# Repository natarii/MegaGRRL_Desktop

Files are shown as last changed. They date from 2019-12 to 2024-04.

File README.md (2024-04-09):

# MegaGRRL Desktop
## Overview
**MegaGRRL Desktop** is a simplified, easier to assemble respin of the original MegaGRRL project. This is intended for those who wish to assemble their own with minimal surface mount soldering, or do not need portability.
## Assembly guide
[Click here for the assembly guide.](https://git.agiri.ninja/natalie/MegaGRRL_Desktop/wikis/Assembly-guide) Bill of materials can be found [here](https://git.agiri.ninja/natalie/MegaGRRL_Desktop/wikis/BOM)
## Firmware flashing/changes
The portable and desktop MegaGRRL versions share a single codebase, contained in the [normal MegaGRRL repo](https://git.agiri.ninja/natalie/megagrrl). Before compiling, `main/hal.h` must be edited to specify that the desktop version is built. More details on this are available in the MegaGRRL project repo's readme.

A simplified flashing guide is available for Windows users [here](https://git.agiri.ninja/snippets/3).
## PCB manufacturing considerations
The board is a fairly standard 2-layer board. Please ensure that your PCB manufacturer handles the plated slots on the headphone jack correctly. The DRC rules are set for tented vias - these are preferable for aesthetics, but are otherwise not required. Please note if exporting your own gerbers that the art for the top and bottom of the PCB are on layers 200 (top) and 201 (bottom). Pre-exported gerbers for JLCPCB can be found in the `gerbers/` directory.
## 3D Printing
`mgd_base.stl` is an STL file for a 3D-printable baseplate for the MegaGRRL Desktop board. This provides a nice flat bottom surface and also supports the PCB underneath areas that undergo flexing (buttons, IC sockets). The original OpenSCAD source file is also available. 100% infill is recommended, and printing with a brim may help bed adhesion. Supports are needed due to the recessed screw holes. **The STL and SCAD files have recently been updated to be sized in mm instead of mil.** Previously they required scaling before printing, but this should no longer be required. If you are using a paid 3D printing service, please double-check the size before ordering!
## License
The schematic, PCB, and baseplate are licensed under CERN-OHL-S v2.
## Beware Fake Chips!

[WIP guide on detecting fake chips](https://git.agiri.ninja/natalie/MegaGRRL_Desktop/-/wikis/Identifying-fake-YM2612s)

Many of the YM2612s being sold on eBay are fake. Chips are very often remarked to make them appear new, and that has been ongoing for a long time, but recently myself and friends have received completely fake, non-working chips from multiple eBay sellers. If you are unsure about chips you received, email me a photo and I'll check them out. Also, I have had much better luck receiving legit YM3438s from eBay, so that may be the way to go. I recommend YM3438 anyway due to its improved sound quality.

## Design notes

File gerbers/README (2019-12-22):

This directory contains pre-made gerber files. They have not been tested with any PCB fab other than JLCPCB. Use at your own risk! It is recommended to export your own gerbers and ensure they match your fab's specs.

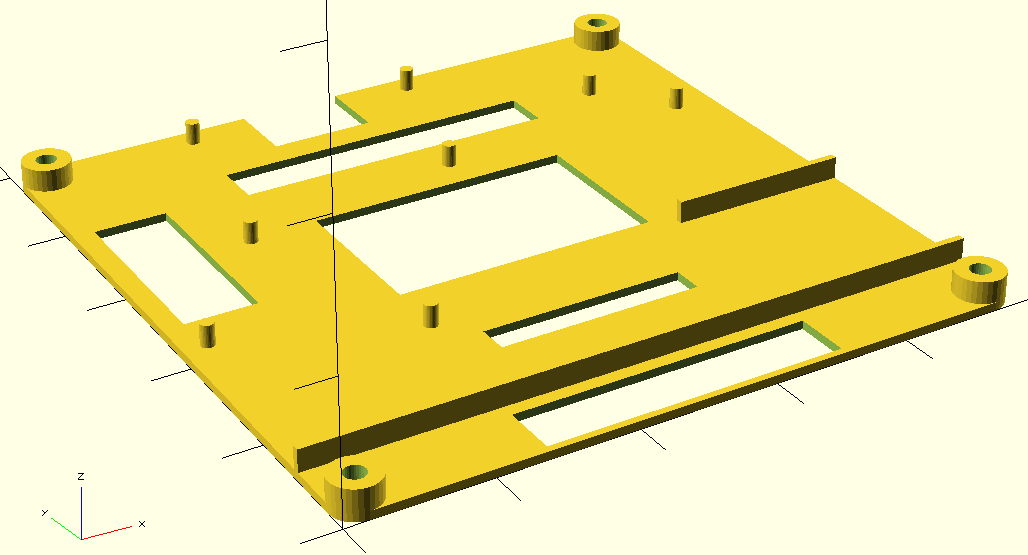
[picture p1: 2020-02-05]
mgd_base.png

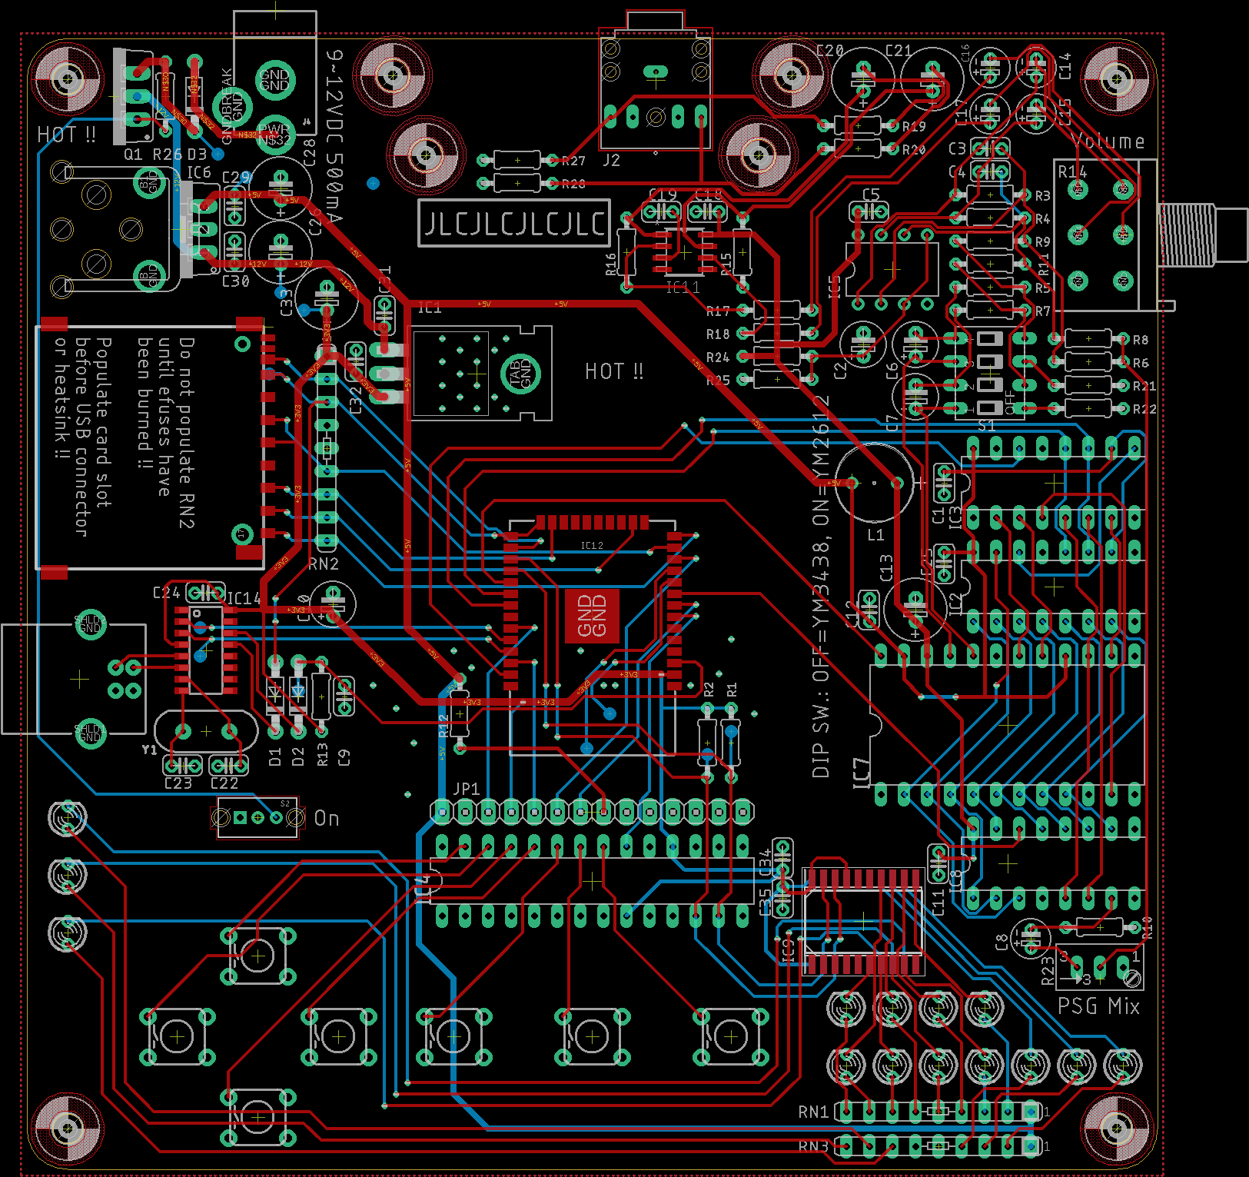
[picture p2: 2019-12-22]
pcb.png

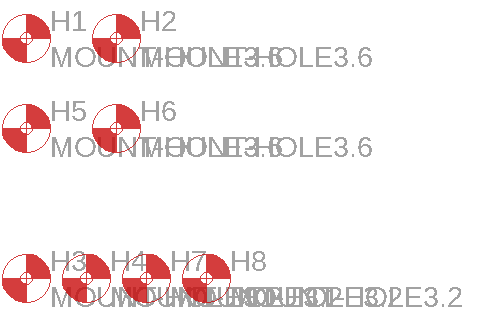
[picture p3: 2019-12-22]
sch_png/sch_7_misc.png

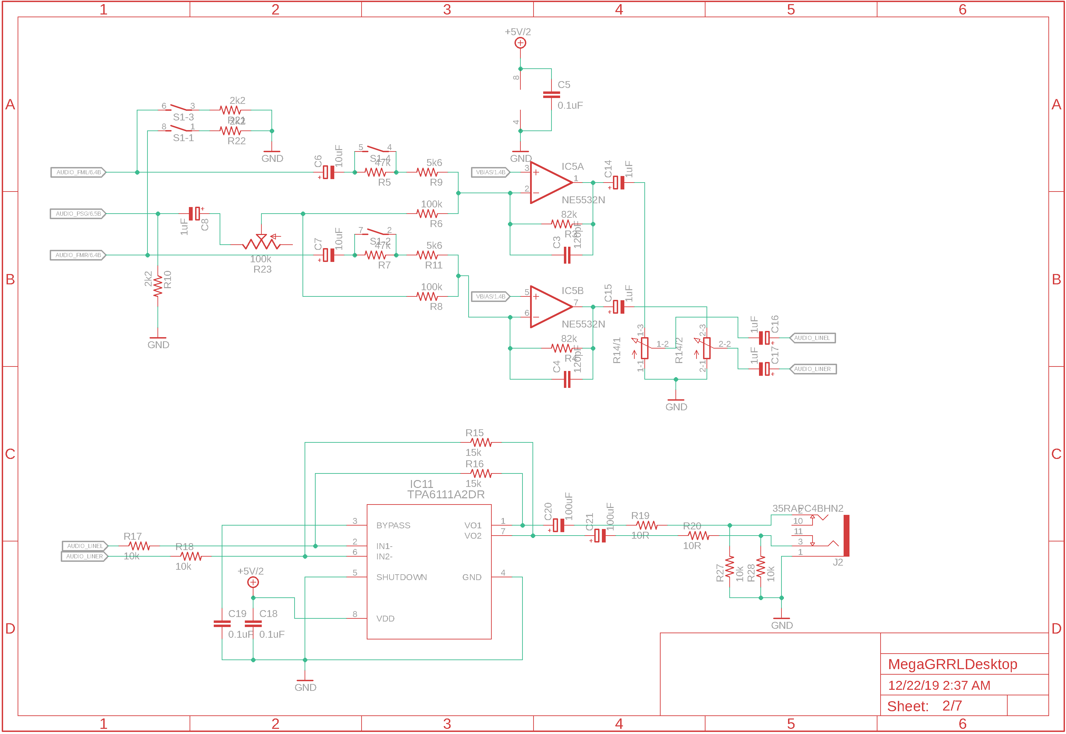
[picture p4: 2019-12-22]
sch_png/sch_2_audio.png

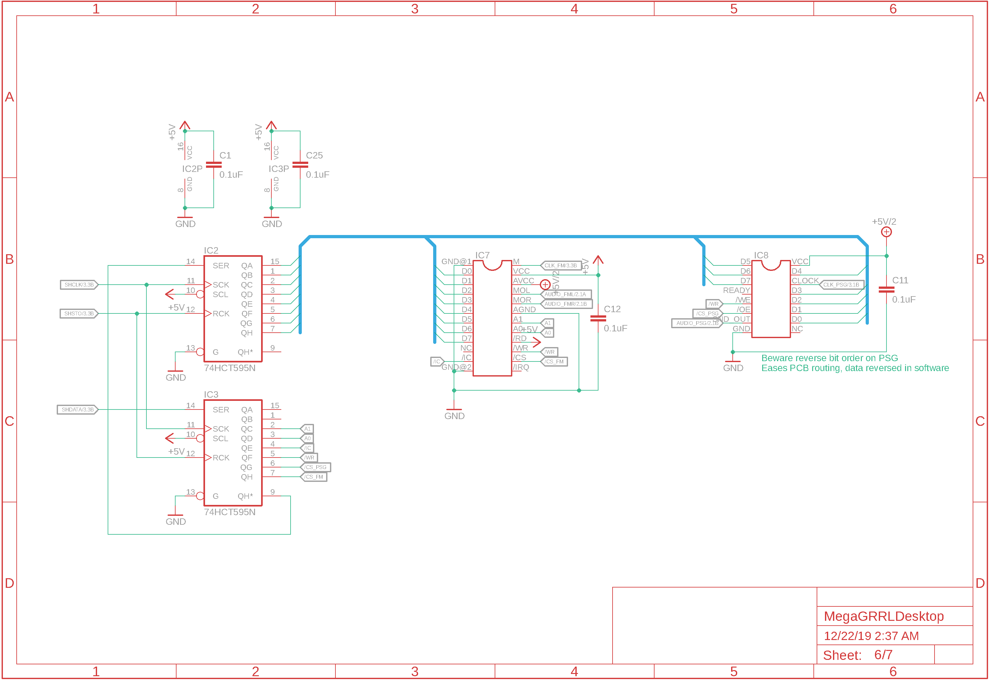
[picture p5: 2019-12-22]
sch_png/sch_6_sound_chips_bus.png

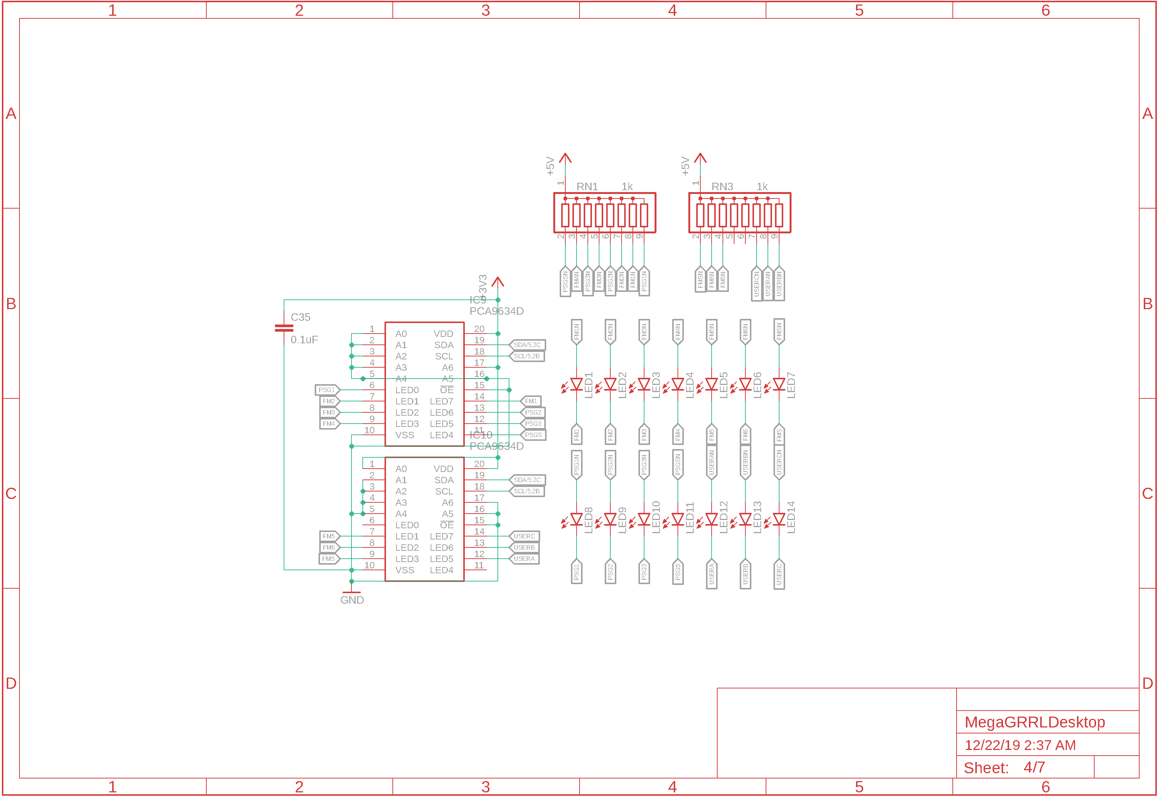
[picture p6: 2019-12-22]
sch_png/sch_4_led_drivers.png

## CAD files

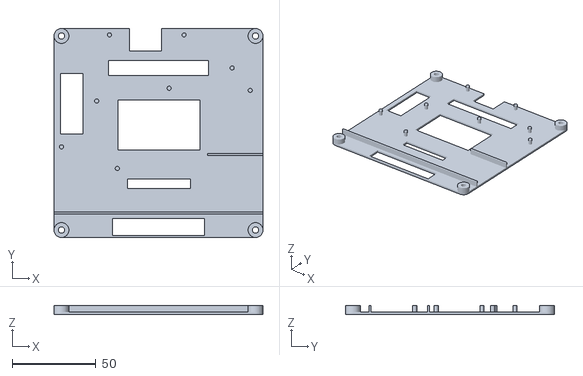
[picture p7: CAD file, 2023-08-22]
mgd_base.stl
124.5 x 124.5 x 5.59

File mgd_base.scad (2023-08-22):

$fn = 32;
$pcbwidth = 4900;
$pcbheight = 4900;
$pcbbottomgap = 160;
$keysupporty = 575;
$keysupportthickness = 50;
$fmsupporty = 1925;
$fmsupportwidth = 1300;
$fmsupportthickness = 50;
$holefactor = 50;
$thickness = 60;

scale([0.0254, 0.0254, 0.0254]) {
    difference() {
        union(){
            //solids
            cube([$pcbwidth, $pcbheight, $thickness]);
            translate([0,$keysupporty-($keysupportthickness/2),$thickness]) cube([$pcbwidth, $keysupportthickness, $pcbbottomgap]);
            translate([$pcbwidth-$fmsupportwidth,$fmsupporty,$thickness]) cube([$fmsupportwidth, $fmsupportthickness, $pcbbottomgap]);
            translate([1485, 1621, $thickness]) cylinder(h=$pcbbottomgap, d=100, center=false);
            translate([2700, 3500, $thickness]) cylinder(h=$pcbbottomgap, d=100, center=false);
            translate([1000, 3200, $thickness]) cylinder(h=$pcbbottomgap, d=100, center=false);
            translate([1300, 4750, $thickness]) cylinder(h=$pcbbottomgap, d=100, center=false);
            translate([3050, 4750, $thickness]) cylinder(h=$pcbbottomgap, d=100, center=false);
            translate([175, 2125, $thickness]) cylinder(h=$pcbbottomgap, d=100, center=false);
            translate([4175, 3975, $thickness]) cylinder(h=$pcbbottomgap, d=100, center=false);
            translate([4600, 3450, $thickness]) cylinder(h=$pcbbottomgap, d=100, center=false);
            translate([175, 175, 0]) cylinder(d=350,h=$thickness+$pcbbottomgap);
            translate([$pcbwidth-175, 175, 0]) cylinder(d=350,h=$thickness+$pcbbottomgap);
            translate([$pcbwidth-175, $pcbheight-175, 0]) cylinder(d=350,h=$thickness+$pcbbottomgap);
            translate([175, $pcbheight-175, 0]) cylinder(d=350,h=$thickness+$pcbbottomgap);
        }
        
        //kl+logo 1550,2025 3475,3175
        cubexy(1550,2100,3375,3175,0,$thickness);
        //aliensoldier 1325,3750 3675,4100
        cubexy(1325,3850,3575,4100,0,$thickness);
        //DC 1875,4325 2575,4900
        cubexy(1825,4425,2475,4850,0,$thickness);
        //url 1775,1125 3225,1300
        cubexy(1775,1200,3150,1325,0,$thickness);
        //ver 200,2475 625,3800
        cubexy(200,2475,625,3800,0,$thickness);
        //serno
        cubexy(1425,100,3475,400,0,$thickness);
        
        posipostBL();
        posipostBR();
        posipostTL();
        posipostTR();
        
        translate([175, 175, 0]) cylinder(d=150,h=$thickness+$pcbbottomgap);
        translate([$pcbwidth-175, 175, 0]) cylinder(d=150,h=$thickness+$pcbbottomgap);
        translate([$pcbwidth-175, $pcbheight-175, 0]) cylinder(d=150,h=$thickness+$pcbbottomgap);
        translate([175, $pcbheight-175, 0]) cylinder(d=150,h=$thickness+$pcbbottomgap);
        
        translate([175, 175, 0]) cylinder(d=250,h=125);
        translate([$pcbwidth-175, 175, 0]) cylinder(d=250,h=125);
        translate([$pcbwidth-175, $pcbheight-175, 0]) cylinder(d=250,h=125);
        translate([175, $pcbheight-175, 0]) cylinder(d=250,h=125);
    }
}

module cubexy(x1,y1,x2,y2,zo,z) {
    translate([x1-$holefactor,y1-$holefactor,zo]) cube([(x2-x1)+($holefactor*2),(y2-y1)+($holefactor*2),z]);
}

//i gave myself a headache trying to think of the math to do this with rotation, so i made this mess instead, which will no doubt transfer my headache to the reader
module posipostBL() {
    difference() {
        cube([350/2,350/2,$thickness]);
        translate([(350/2),(350/2),0]) cylinder(d=350,h=$thickness,center=false);
    }
}
module posipostBR() {
    difference() {
        translate([$pcbwidth-(350/2),0,0]) cube([350/2,350/2,$thickness]);
        translate([$pcbwidth-(350/2),(350/2),0]) cylinder(d=350,h=$thickness,center=false);
    }
}
module posipostTR() {
    difference() {
        translate([$pcbwidth-(350/2),$pcbheight-(350/2),0]) cube([350/2,350/2,$thickness]);
        translate([$pcbwidth-(350/2),$pcbheight-(350/2),0]) cylinder(d=350,h=$thickness,center=false);
    }
}
module posipostTL() {
    difference() {
        translate([0,$pcbheight-(350/2),0]) cube([350/2,350/2,$thickness]);
        translate([(350/2),$pcbheight-(350/2),0]) cylinder(d=350,h=$thickness,center=false);
    }
}

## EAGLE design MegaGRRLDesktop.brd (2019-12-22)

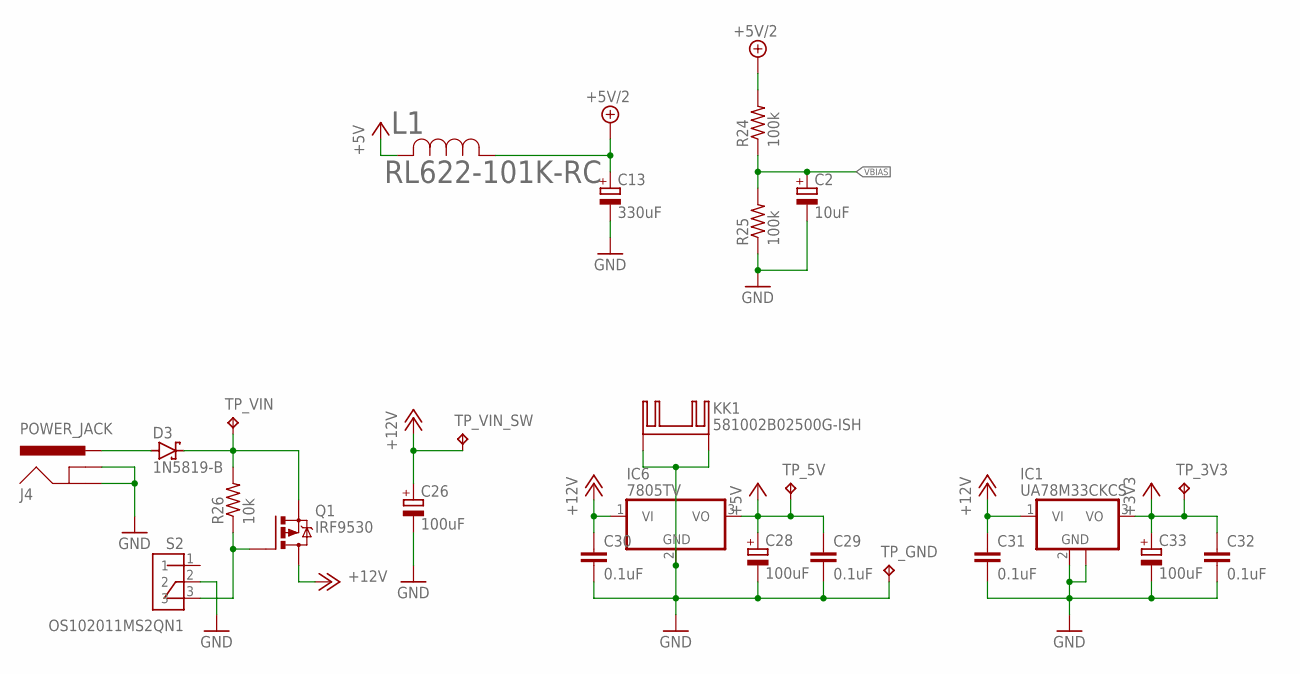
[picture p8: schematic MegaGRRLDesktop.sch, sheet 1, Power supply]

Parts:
C2: 10uF; E2,5-5
C13: 330uF; E2,5-7
C26, C28, C33: 100uF; E2,5-7
C29, C30, C31, C32: 0.1uF; C025-024X044
D3: 1N5819-B; DO41-7.6
IC1: UA78M33CKCS; TO220H
IC6: 7805TV; TO220V
J4: POWER_JACK; POWER_JACK_PTH
KK1: 581002B02500G-ISH
L1: RL622-101K-RC; RL622_SERIES
Q1: IRF9530; TO220BV
R24, R25: 100k; 0204/7
R26: 10k; 0204/7
S2: OS102011MS2QN1; SW_OS102011MS2QN1
TP_3V3, TP_5V: TPB1,27; B1,27
TP_GND: TPB1,27; B1,27
TP_VIN: TPB1,27; B1,27
TP_VIN_SW: TPB1,27; B1,27

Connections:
+3V3: C32.1, C33.+, IC1.3 (VO), TP_3V3.TP; also elsewhere on the board
+5V: C28.+, C29.1, IC6.3 (VO), L1.2, TP_5V.TP; also elsewhere on the board
+5V/2: C13.+, L1.1, R24.2; also elsewhere on the board
+12V: C26.+, C30.1, C31.1, IC1.1 (VI), IC6.1 (VI), Q1.D, TP_VIN_SW.TP
GND: C2.-, C13.-, C26.-, C28.-, C29.2, C30.2, C31.2, C32.2, C33.-, IC1.2 (GND), IC1.TAB (GND), IC6.2 (GND), J4.GND, J4.GNDBREAK, KK1.B, KK1.B1, R25.1, S2.2, TP_GND.TP; also elsewhere on the board
unnamed: D3.C, Q1.S, R26.2, TP_VIN.TP
unnamed: Q1.G, R26.1, S2.3
unnamed: D3.A, J4.PWR
VBIAS: C2.+, R24.1, R25.2; also elsewhere on the board

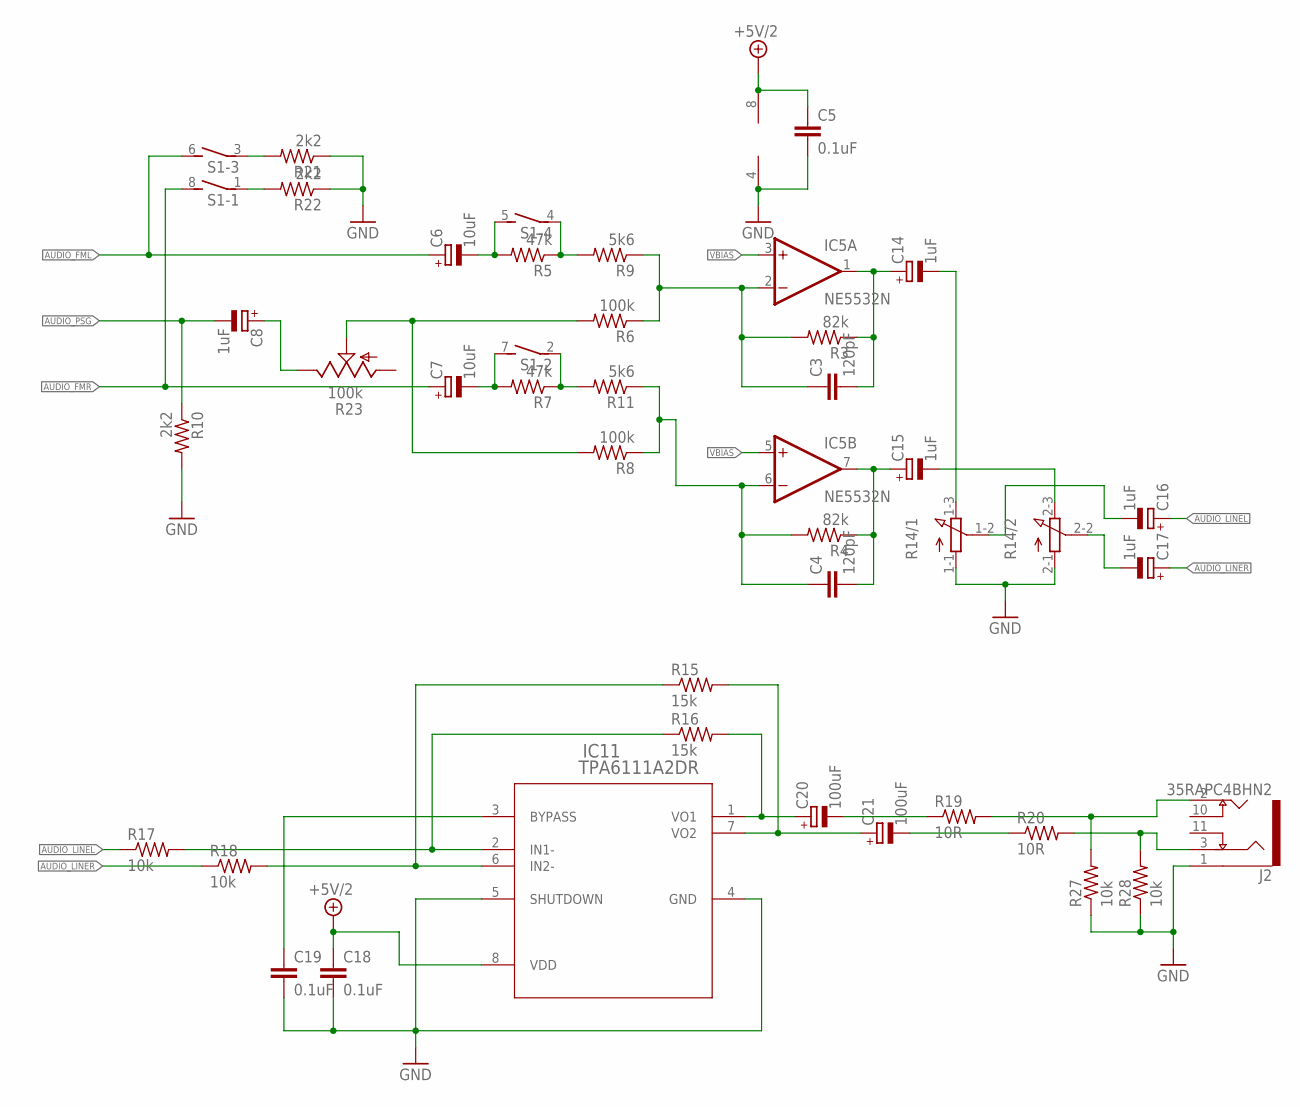
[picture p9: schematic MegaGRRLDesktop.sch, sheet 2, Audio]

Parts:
C3, C4: 120pF; C025-024X044
C5, C18, C19: 0.1uF; C025-024X044
C6, C7: 10uF; E2,5-5
C8, C14, C15, C16, C17: 1uF; E2-4
C20, C21: 100uF; E2,5-7
IC5: NE5532N; DIL08
IC11: TPA6111A2DR; D8
J2: 35RAPC4BHN2; SWITCHCRAFT_35RAPC4BHN2
R3, R4: 82k; 0204/7
R5, R7: 47k; 0204/7
R6, R8: 100k; 0204/7
R9, R11: 5k6; 0204/7
R10, R21, R22: 2k2; 0204/7
R14: 3RP/1610G
R15, R16: 15k; 0204/7
R17, R18, R27, R28: 10k; 0204/7
R19, R20: 10R; 0204/7
R23: 100k; S64W
S1: DIP04S

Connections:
+5V/2: C5.1, C18.1, IC5.8 (V+), IC11.8 (VDD); also elsewhere on the board
AUDIO_FML: C6.+, S1.6 (2); also elsewhere on the board
AUDIO_FMR: C7.+, S1.8 (2); also elsewhere on the board
AUDIO_LINEL: C16.+, R17.1
AUDIO_LINER: C17.+, R18.1
AUDIO_PSG: C8.-, R10.1; also elsewhere on the board
AUDIO_RAWL: C3.1, IC5.2 (-IN), R3.2, R6.1, R9.1
AUDIO_RAWR: C4.1, IC5.6 (-IN), R4.2, R8.1, R11.1
GND: C5.2, C18.2, C19.2, IC5.4 (V-), IC11.4 (GND), IC11.5 (SHUTDOWN), J2.1 (SLEEVE), R10.2, R14.1-1 (A), R14.2-1 (A), R21.1, R22.1, R27.1, R28.1; also elsewhere on the board
unnamed: R7.1, R11.2, S1.2 (1)
unnamed: C3.2, C14.+, IC5.1 (OUT), R3.1
unnamed: C4.2, C15.+, IC5.7 (OUT), R4.1
unnamed: C14.-, R14.1-3 (E)
unnamed: R6.2, R8.2, R23.S
unnamed: C7.-, R7.2, S1.7 (2)
unnamed: C6.-, R5.2, S1.5 (2)
unnamed: C15.-, R14.2-3 (E)
unnamed: C16.-, R14.1-2 (S)
unnamed: C17.-, R14.2-2 (S)
unnamed: IC11.2 (IN1-), R16.1, R17.2
unnamed: IC11.6 (IN2-), R15.1, R18.2
unnamed: C20.+, IC11.1 (VO1), R16.2
unnamed: C21.+, IC11.7 (VO2), R15.2
unnamed: C19.1, IC11.3 (BYPASS)
unnamed: J2.2 (TIP), R19.2, R27.2
unnamed: C20.-, R19.1
unnamed: C21.-, R20.1
unnamed: J2.3 (RING), R20.2, R28.2
unnamed: R5.1, R9.2, S1.4 (1)
unnamed: R21.2, S1.3 (1)
unnamed: R22.2, S1.1
unnamed: C8.+, R23.E
VBIAS: IC5.3 (+IN), IC5.5 (+IN); also elsewhere on the board

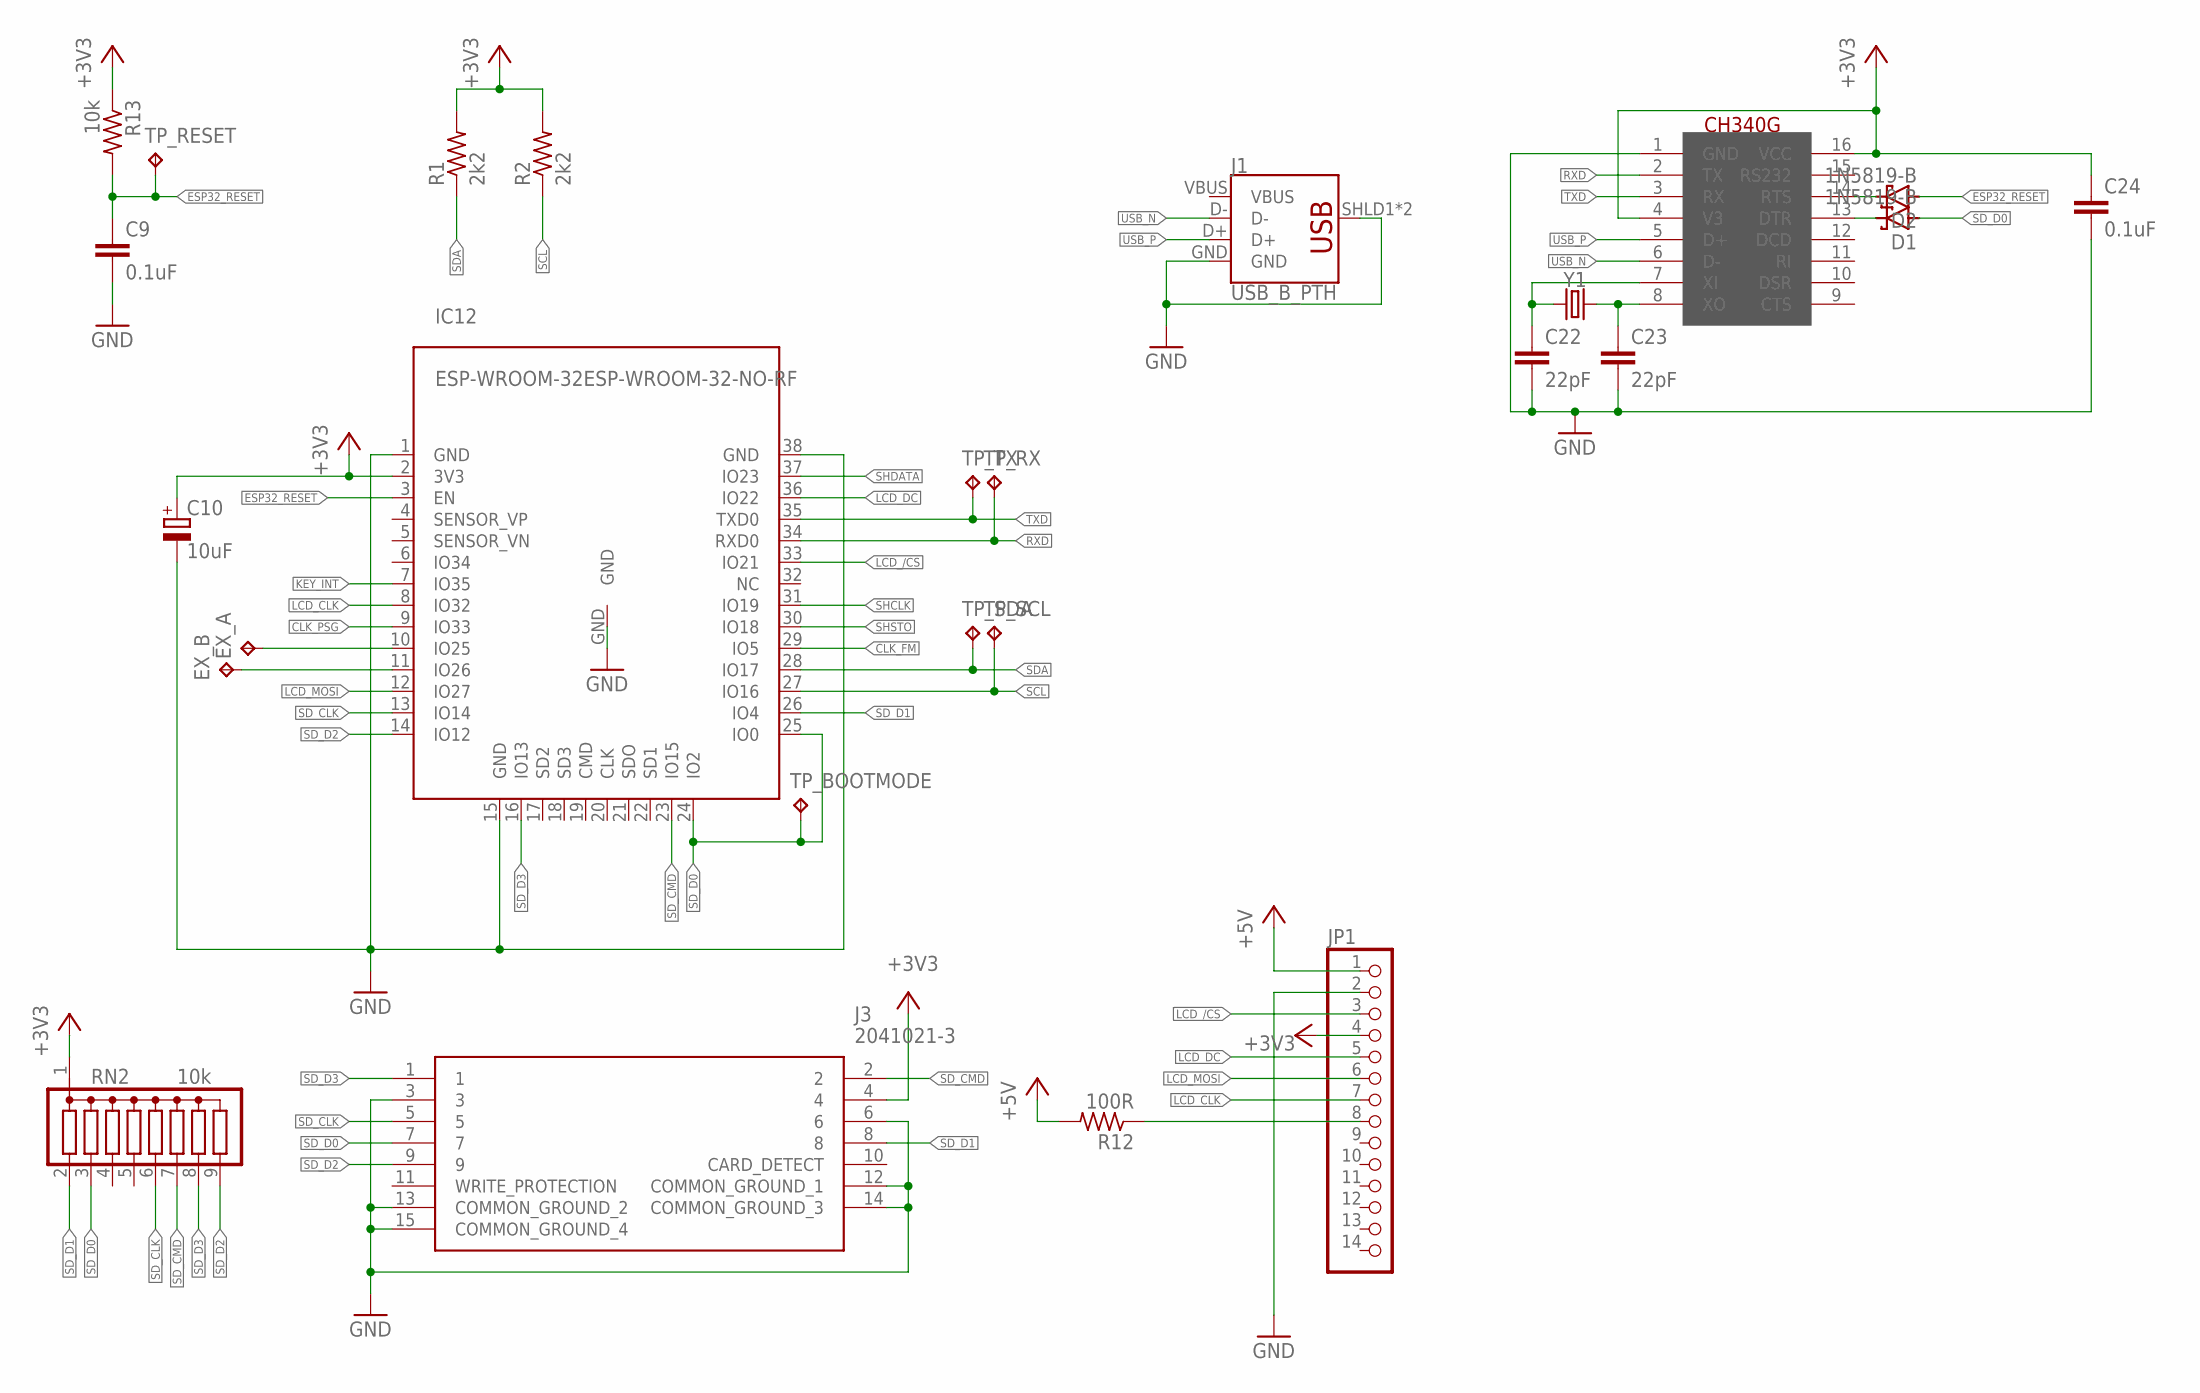
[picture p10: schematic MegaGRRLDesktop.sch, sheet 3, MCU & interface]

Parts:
C9, C24: 0.1uF; C025-024X044
C10: 10uF; E2,5-5
C22, C23: 22pF; C025-024X044
D1, D2: 1N5819-B; DO41-7.6
EX_A: TPB1,27; B1,27
EX_B: TPB1,27; B1,27
IC12: ESP-WROOM-32ESP-WROOM-32-NO-RF; ESP-WROOM-32-NO-RF
IC14: CH340G; SOIC16
J1: USB_B_PTH; USB-B-PTH
J3: 2041021-3; 2041021-3_2
JP1: ILI9341_2_4
R1, R2: 2k2; 0204/7
R12: 100R; 0204/7
R13: 10k; 0204/7
RN2: 10k; SIL9
TP_BOOTMODE: TPB1,27; B1,27
TP_RESET: TPB1,27; B1,27
TP_RX: TPB1,27; B1,27
TP_SCL: TPB1,27; B1,27
TP_SDA: TPB1,27; B1,27
TP_TX: TPB1,27; B1,27
Y1: CRYSTALPTH-HC49US; HC49US

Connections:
+3V3: C10.+, C24.1, IC12.2 (3V3), IC14.4 (V3), IC14.16 (VCC), J3.4, JP1.4, R1.2, R2.2, R13.1, RN2.1; also elsewhere on the board
+5V: JP1.1, R12.2; also elsewhere on the board
CLK_FM: IC12.29 (IO5); also elsewhere on the board
CLK_PSG: IC12.9 (IO33); also elsewhere on the board
ESP32_RESET: C9.1, D2.A, IC12.3 (EN), R13.2, TP_RESET.TP
GND: C9.2, C10.-, C22.2, C23.2, C24.2, IC12.1 (GND), IC12.15 (GND), IC12.38 (GND), IC12.GND, IC14.1 (GND), J1.GND, J1.SHLD1 (SHIELD), J1.SHLD2 (SHIELD), J3.3, J3.6, J3.12 (COMMON_GROUND_1), J3.13 (COMMON_GROUND_2), J3.14 (COMMON_GROUND_3), J3.15 (COMMON_GROUND_4), JP1.2; also elsewhere on the board
KEY_INT: IC12.7 (IO35); also elsewhere on the board
LCD_/CS: IC12.33 (IO21), JP1.3
LCD_CLK: IC12.8 (IO32), JP1.7
LCD_DC: IC12.36 (IO22), JP1.5
LCD_MOSI: IC12.12 (IO27), JP1.6
unnamed: C23.1, IC14.8 (XO), Y1.2
unnamed: C22.1, IC14.7 (XI), Y1.1
unnamed: JP1.8, R12.1
unnamed: D1.C, IC14.13 (DTR)
unnamed: D2.C, IC14.14 (RTS)
unnamed: EX_A.TP, IC12.10 (IO25)
unnamed: EX_B.TP, IC12.11 (IO26)
RXD: IC12.34 (RXD0), IC14.2 (TX), TP_RX.TP
SCL: IC12.27 (IO16), R2.1, TP_SCL.TP; also elsewhere on the board
SDA: IC12.28 (IO17), R1.1, TP_SDA.TP; also elsewhere on the board
SD_CLK: IC12.13 (IO14), J3.5, RN2.6
SD_CMD: IC12.23 (IO15), J3.2, RN2.7
SD_D0: D1.A, IC12.24 (IO2), IC12.25 (IO0), J3.7, RN2.3, TP_BOOTMODE.TP
SD_D1: IC12.26 (IO4), J3.8, RN2.2
SD_D2: IC12.14 (IO12), J3.9, RN2.9
SD_D3: IC12.16 (IO13), J3.1, RN2.8
SHCLK: IC12.31 (IO19); also elsewhere on the board
SHDATA: IC12.37 (IO23); also elsewhere on the board
SHSTO: IC12.30 (IO18); also elsewhere on the board
TXD: IC12.35 (TXD0), IC14.3 (RX), TP_TX.TP
USB_N: IC14.6 (D-), J1.D-
USB_P: IC14.5 (D+), J1.D+
VBUS: J1.VBUS

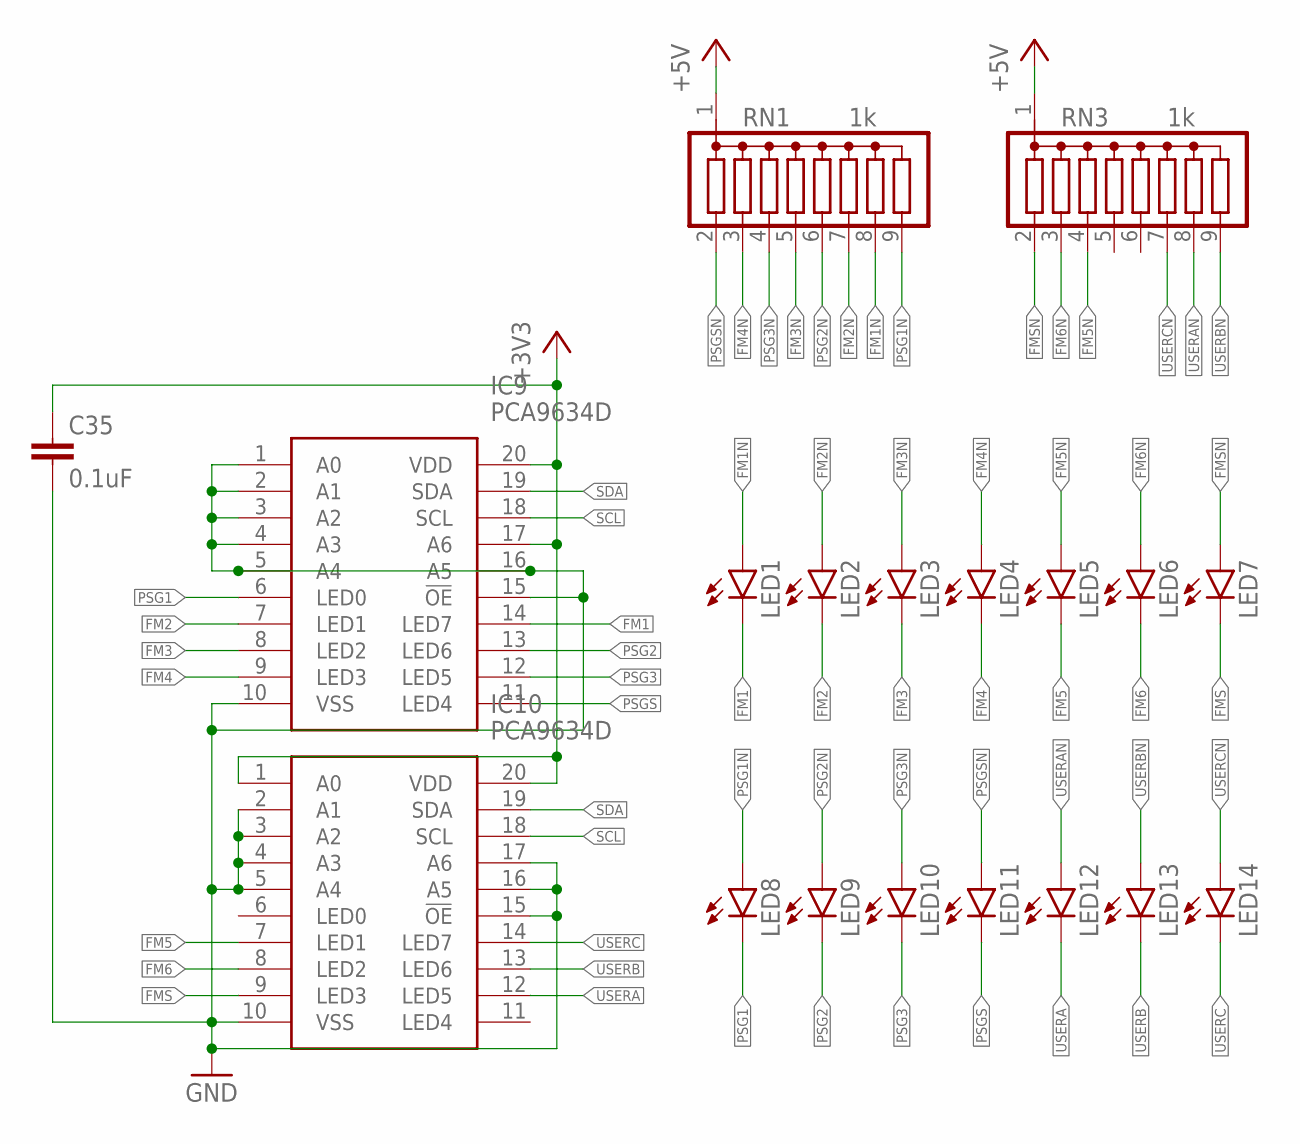
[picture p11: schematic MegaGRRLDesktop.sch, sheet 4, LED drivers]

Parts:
C35: 0.1uF; C025-024X044
IC9, IC10: PCA9634D; SOIC127P1032X265-20N
LED1, LED2, LED3, LED4, LED5, LED6, LED7, LED8, LED9, LED10, LED11, LED12, LED13, LED14: LED3MM
RN1, RN3: 1k; SIL9

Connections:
+3V3: C35.1, IC9.17 (A6), IC9.20 (VDD), IC10.1 (A0), IC10.20 (VDD); also elsewhere on the board
+5V: RN1.1, RN3.1; also elsewhere on the board
FM1: IC9.14 (LED7), LED1.K (C)
FM1N: LED1.A, RN1.8
FM2: IC9.7 (LED1), LED2.K (C)
FM2N: LED2.A, RN1.7
FM3: IC9.8 (LED2), LED3.K (C)
FM3N: LED3.A, RN1.5
FM4: IC9.9 (LED3), LED4.K (C)
FM4N: LED4.A, RN1.3
FM5: IC10.7 (LED1), LED5.K (C)
FM5N: LED5.A, RN3.4
FM6: IC10.8 (LED2), LED6.K (C)
FM6N: LED6.A, RN3.3
FMS: IC10.9 (LED3), LED7.K (C)
FMSN: LED7.A, RN3.2
GND: C35.2, IC9.1 (A0), IC9.2 (A1), IC9.3 (A2), IC9.4 (A3), IC9.5 (A4), IC9.10 (VSS), IC9.15 (!OE), IC9.16 (A5), IC10.2 (A1), IC10.3 (A2), IC10.4 (A3), IC10.5 (A4), IC10.10 (VSS), IC10.15 (!OE), IC10.16 (A5), IC10.17 (A6); also elsewhere on the board
PSG1: IC9.6 (LED0), LED8.K (C)
PSG1N: LED8.A, RN1.9
PSG2: IC9.13 (LED6), LED9.K (C)
PSG2N: LED9.A, RN1.6
PSG3: IC9.12 (LED5), LED10.K (C)
PSG3N: LED10.A, RN1.4
PSGS: IC9.11 (LED4), LED11.K (C)
PSGSN: LED11.A, RN1.2
SCL: IC9.18 (SCL), IC10.18 (SCL); also elsewhere on the board
SDA: IC9.19 (SDA), IC10.19 (SDA); also elsewhere on the board
USERA: IC10.12 (LED5), LED12.K (C)
USERAN: LED12.A, RN3.8
USERB: IC10.13 (LED6), LED13.K (C)
USERBN: LED13.A, RN3.9
USERC: IC10.14 (LED7), LED14.K (C)
USERCN: LED14.A, RN3.7

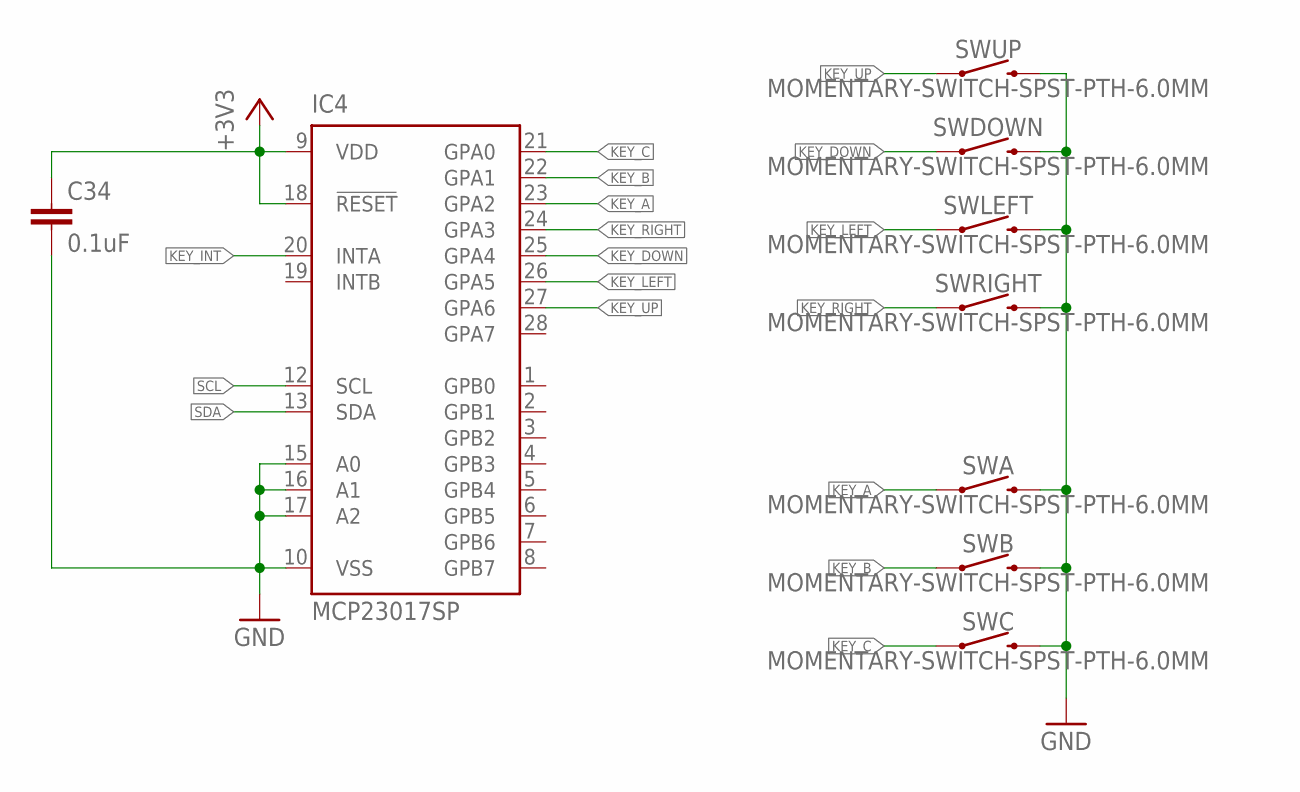
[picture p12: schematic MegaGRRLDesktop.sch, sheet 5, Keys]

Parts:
C34: 0.1uF; C025-024X044
IC4: MCP23017SP; DIL28-3
SWA: MOMENTARY-SWITCH-SPST-PTH-6.0MM; TACTILE_SWITCH_PTH_6.0MM
SWB: MOMENTARY-SWITCH-SPST-PTH-6.0MM; TACTILE_SWITCH_PTH_6.0MM
SWC: MOMENTARY-SWITCH-SPST-PTH-6.0MM; TACTILE_SWITCH_PTH_6.0MM
SWDOWN: MOMENTARY-SWITCH-SPST-PTH-6.0MM; TACTILE_SWITCH_PTH_6.0MM
SWLEFT: MOMENTARY-SWITCH-SPST-PTH-6.0MM; TACTILE_SWITCH_PTH_6.0MM
SWRIGHT: MOMENTARY-SWITCH-SPST-PTH-6.0MM; TACTILE_SWITCH_PTH_6.0MM
SWUP: MOMENTARY-SWITCH-SPST-PTH-6.0MM; TACTILE_SWITCH_PTH_6.0MM

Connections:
+3V3: C34.1, IC4.9 (VDD), IC4.18 (!RESET); also elsewhere on the board
GND: C34.2, IC4.10 (VSS), IC4.15 (A0), IC4.16 (A1), IC4.17 (A2), SWA.3 (2), SWB.3 (2), SWC.3 (2), SWDOWN.3 (2), SWLEFT.3 (2), SWRIGHT.3 (2), SWUP.3 (2); also elsewhere on the board
KEY_A: IC4.23 (GPA2), SWA.1
KEY_B: IC4.22 (GPA1), SWB.1
KEY_C: IC4.21 (GPA0), SWC.1
KEY_DOWN: IC4.25 (GPA4), SWDOWN.1
KEY_INT: IC4.20 (INTA); also elsewhere on the board
KEY_LEFT: IC4.26 (GPA5), SWLEFT.1
KEY_RIGHT: IC4.24 (GPA3), SWRIGHT.1
KEY_UP: IC4.27 (GPA6), SWUP.1
SCL: IC4.12 (SCL); also elsewhere on the board
SDA: IC4.13 (SDA); also elsewhere on the board

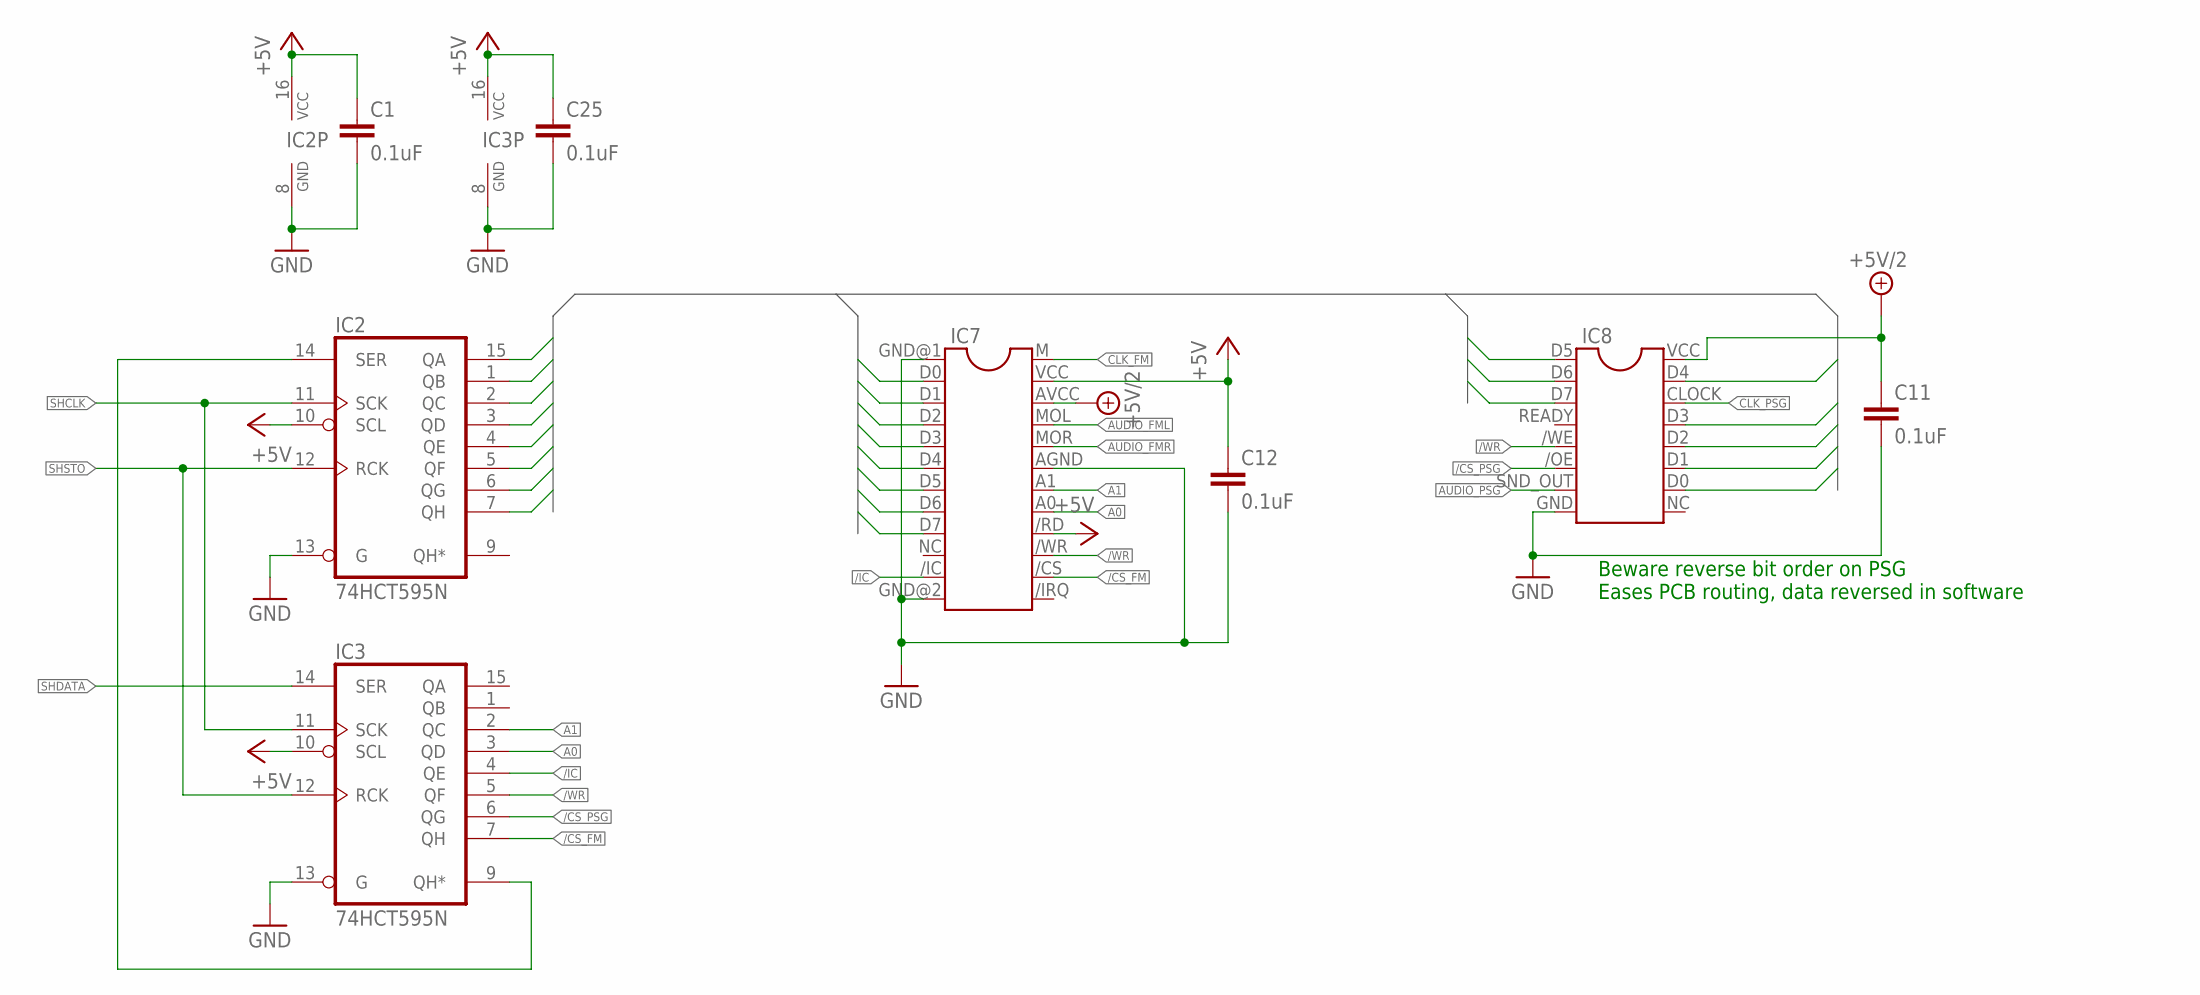
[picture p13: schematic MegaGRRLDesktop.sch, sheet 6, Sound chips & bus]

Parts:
C1, C11, C12, C25: 0.1uF; C025-024X044
IC2, IC3: 74HCT595N; DIL16
IC7: YM2612
IC8: SN76489

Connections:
+5V: C1.1, C12.1, C25.1, IC2.10 (SCL), IC2.16 (VCC), IC3.10 (SCL), IC3.16 (VCC), IC7./RD, IC7.VCC; also elsewhere on the board
+5V/2: C11.1, IC7.AVCC, IC8.VCC; also elsewhere on the board
/CS_FM: IC3.7 (QH), IC7./CS
/CS_PSG: IC3.6 (QG), IC8./OE
/IC: IC3.4 (QE), IC7./IC
/WR: IC3.5 (QF), IC7./WR, IC8./WE
A0: IC3.3 (QD), IC7.A0
A1: IC3.2 (QC), IC7.A1
AUDIO_FML: IC7.MOL; also elsewhere on the board
AUDIO_FMR: IC7.MOR; also elsewhere on the board
AUDIO_PSG: IC8.SND_OUT; also elsewhere on the board
CLK_FM: IC7.M; also elsewhere on the board
CLK_PSG: IC8.CLOCK; also elsewhere on the board
D0: IC2.15 (QA), IC7.D0, IC8.D7
D1: IC2.1 (QB), IC7.D1, IC8.D6
D2: IC2.2 (QC), IC7.D2, IC8.D5
D3: IC2.3 (QD), IC7.D3, IC8.D4
D4: IC2.4 (QE), IC7.D4, IC8.D3
D5: IC2.5 (QF), IC7.D5, IC8.D2
D6: IC2.6 (QG), IC7.D6, IC8.D1
D7: IC2.7 (QH), IC7.D7, IC8.D0
GND: C1.2, C11.2, C12.2, C25.2, IC2.8 (GND), IC2.13 (G), IC3.8 (GND), IC3.13 (G), IC7.AGND, IC7.GND@1 (GND), IC7.GND@2 (GND), IC8.GND; also elsewhere on the board
unnamed: IC2.14 (SER), IC3.9 (QH*)
SHCLK: IC2.11 (SCK), IC3.11 (SCK); also elsewhere on the board
SHDATA: IC3.14 (SER); also elsewhere on the board
SHSTO: IC2.12 (RCK), IC3.12 (RCK); also elsewhere on the board

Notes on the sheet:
Beware reverse bit order on PSG Eases PCB routing, data reversed in software

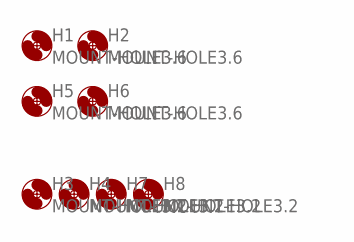
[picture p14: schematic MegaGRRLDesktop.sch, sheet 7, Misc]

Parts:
H1, H2, H5, H6: MOUNT-HOLE3.6; 3,6
H3, H4, H7, H8: MOUNT-HOLE3.2; 3,2

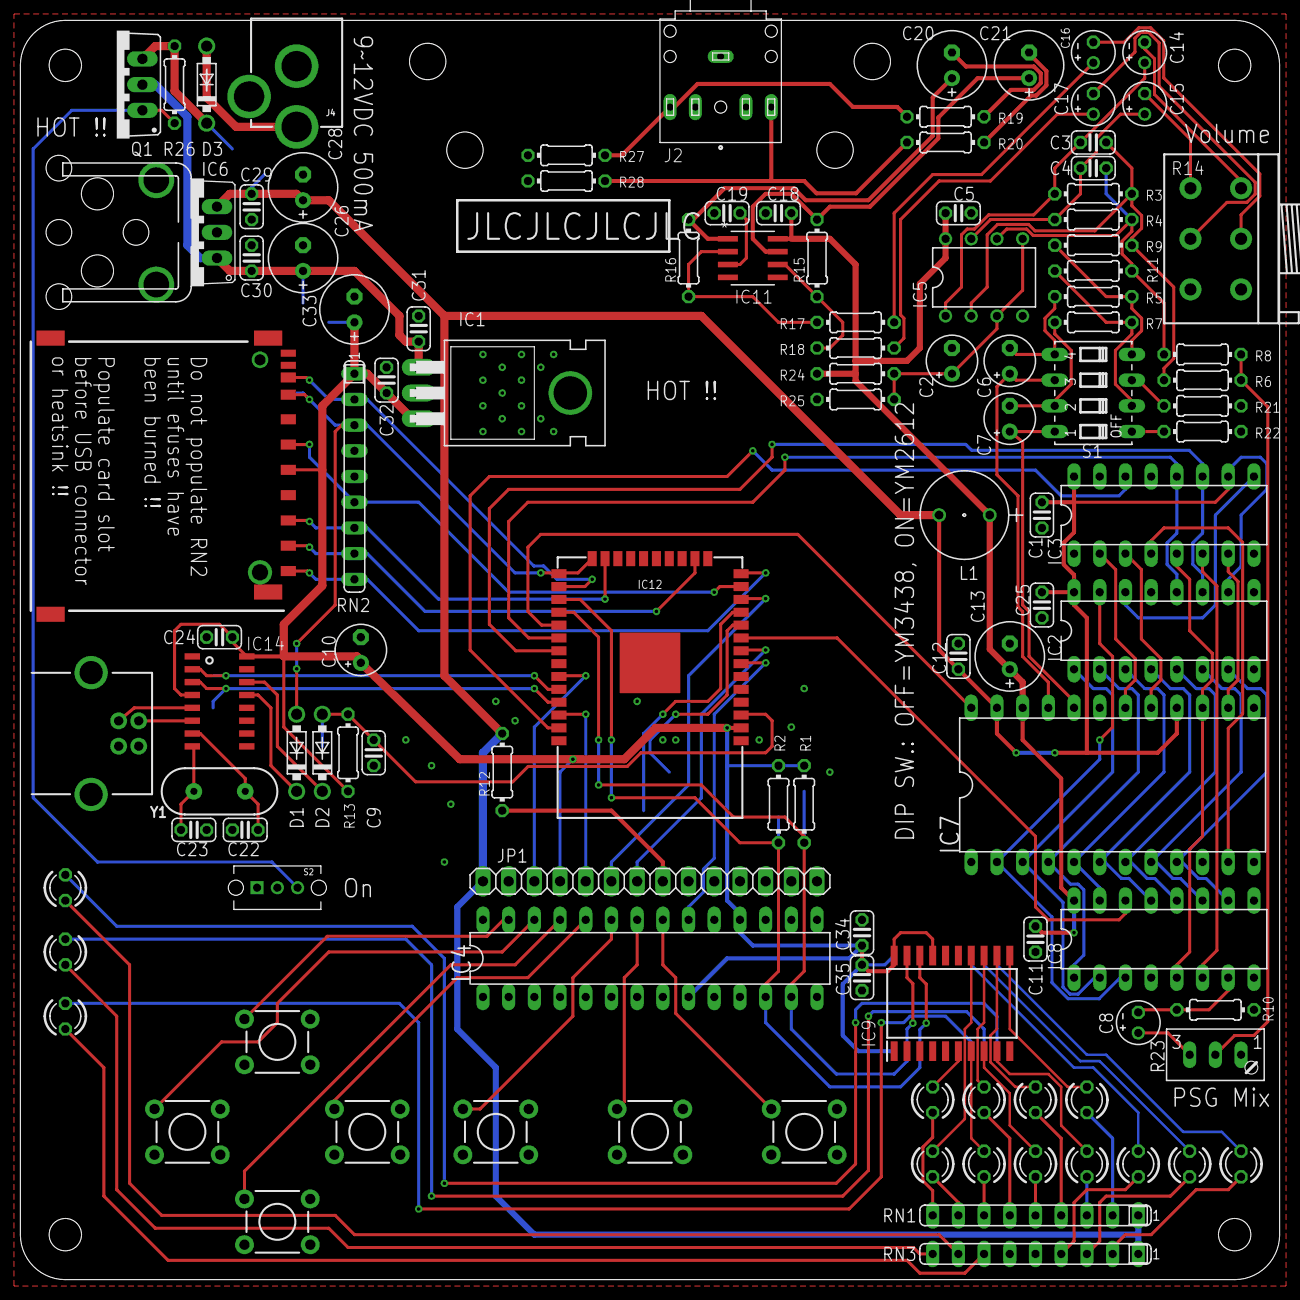
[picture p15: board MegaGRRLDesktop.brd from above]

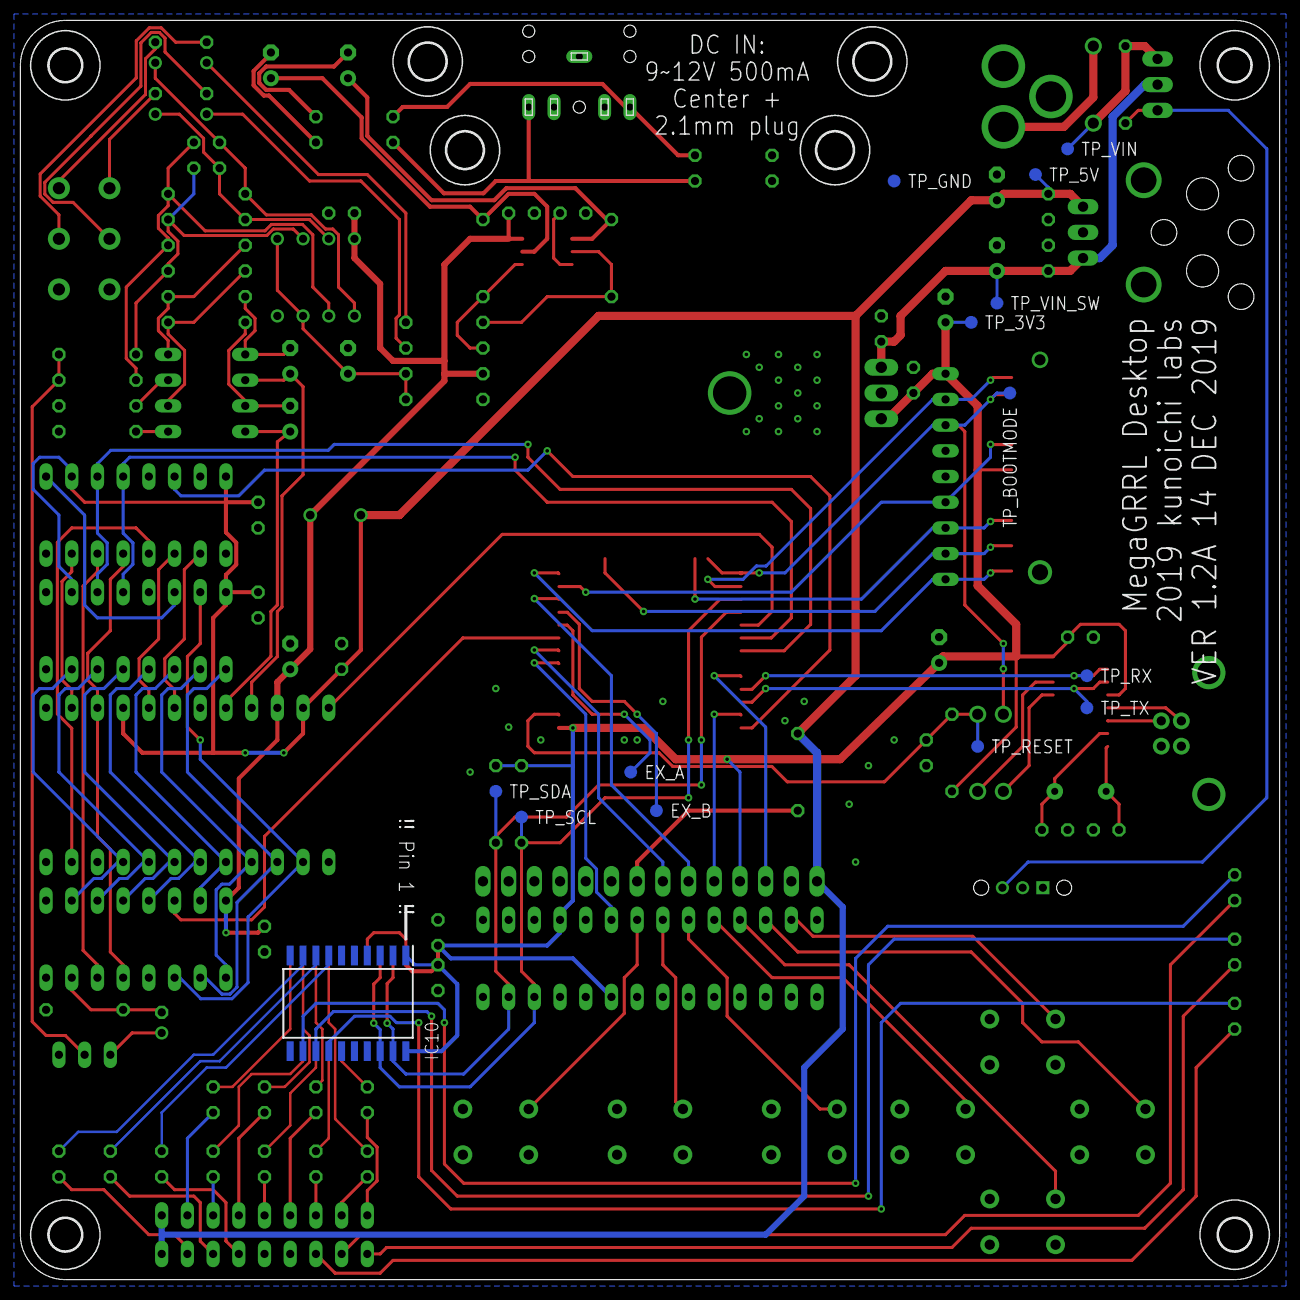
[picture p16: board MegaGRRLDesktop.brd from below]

Board: 2 copper layers, 124.5 x 124.5 mm, 134 parts (22 on the bottom side), 119 nets.

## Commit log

2019-12-14 commit pcb
    [MegaGRRLDesktop.brd]
2019-12-22 fix 74HCT595
    [MegaGRRLDesktop.brd]
2019-12-22 commit schematic
    [MegaGRRLDesktop.sch]
2019-12-22 add premade gerbers
2019-12-22 add pcb image
2019-12-22 add schematic images
2019-12-24 add baseplate files
    [mgd_base.scad]
2020-02-05 commit STL files for baseplate
    [mgd_base.stl]
2023-08-22 Bake in the mil to mm scaling for mgd_base
    [mgd_base.scad, mgd_base.stl]

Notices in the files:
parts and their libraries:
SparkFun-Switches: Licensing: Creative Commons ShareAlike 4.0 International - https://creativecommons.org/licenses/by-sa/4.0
